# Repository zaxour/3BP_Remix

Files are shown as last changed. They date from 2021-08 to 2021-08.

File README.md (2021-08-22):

# 3BP_Remix
Modified version of Tian Feng/dB_Electronics triple bypass v2 board

Incorporates 5.6k pull up resistors for the RGB lines, as Model 1 3BP installs lift the VDP pins to isolate them from the Genesis/MD PCB. Based on research by Tian Feng, and subsequently verified by myself by looking at all available schematics for the Model 1 Genesis/MD, this causes a loss of fidelity in color transitions.

The positioning of the Mini DIN has also been adjusted to fit alongside the Model 1's existing video connector.

Files provided are compatible with Autodesk Eagle (Fusion 360).

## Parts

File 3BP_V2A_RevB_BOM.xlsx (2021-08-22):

Qty | Value | Package | Parts
6 | 0.1u | C0603 | C1, C2, C3, C4, C5, C6 | v
2 | 150p | C0603 | C18, C19 | v
6 | 1u | C0603 | C10, C11, C12, C13, C14, C15 | v
2 | 10u | C0805 | C9, C16 | v
1 | 10u | C1206 | C17 | v
1 | 22u | C1206 | C7 | v
1 | 220u | CT3528 | C8 | v
2 | 47u | CT3528 | C21, C22 | v
1 | MD-90SM | MD90SM | CN1
2 | 100k | R0603 | R29, R32 | v
4 | 10k | R0603 | R26, R27, R30, R33 | v
2 | 130k | R0603 | R28, R31 | v
4 | 1k | R0603 | R6, R7, R8, R9 | v
2 | 2.2k | R0603 | R1, R15 | v
6 | 210k | R0603 | R20, R21, R22, R23, R24, R25 | v
2 | 300k | R0603 | R34, R35 | v
2 | 330 | R0603 | R36, R37 | v
1 | 4.7k | R0603 | R10 | v
7 | 5.62k | R0603 | R2, R3, R4, R5, R38, R39, R40 | v
5 | 75 | R0603 | R11, R13, R14, R17, R18 | v
1 | 750 | R0603 | R16 | v
1 | TL972 | SOIC8 | IC2 | v
1 | THS7374IPWR | TSSOP14 | IC1
https://www.digikey.com/short/43w8t24t

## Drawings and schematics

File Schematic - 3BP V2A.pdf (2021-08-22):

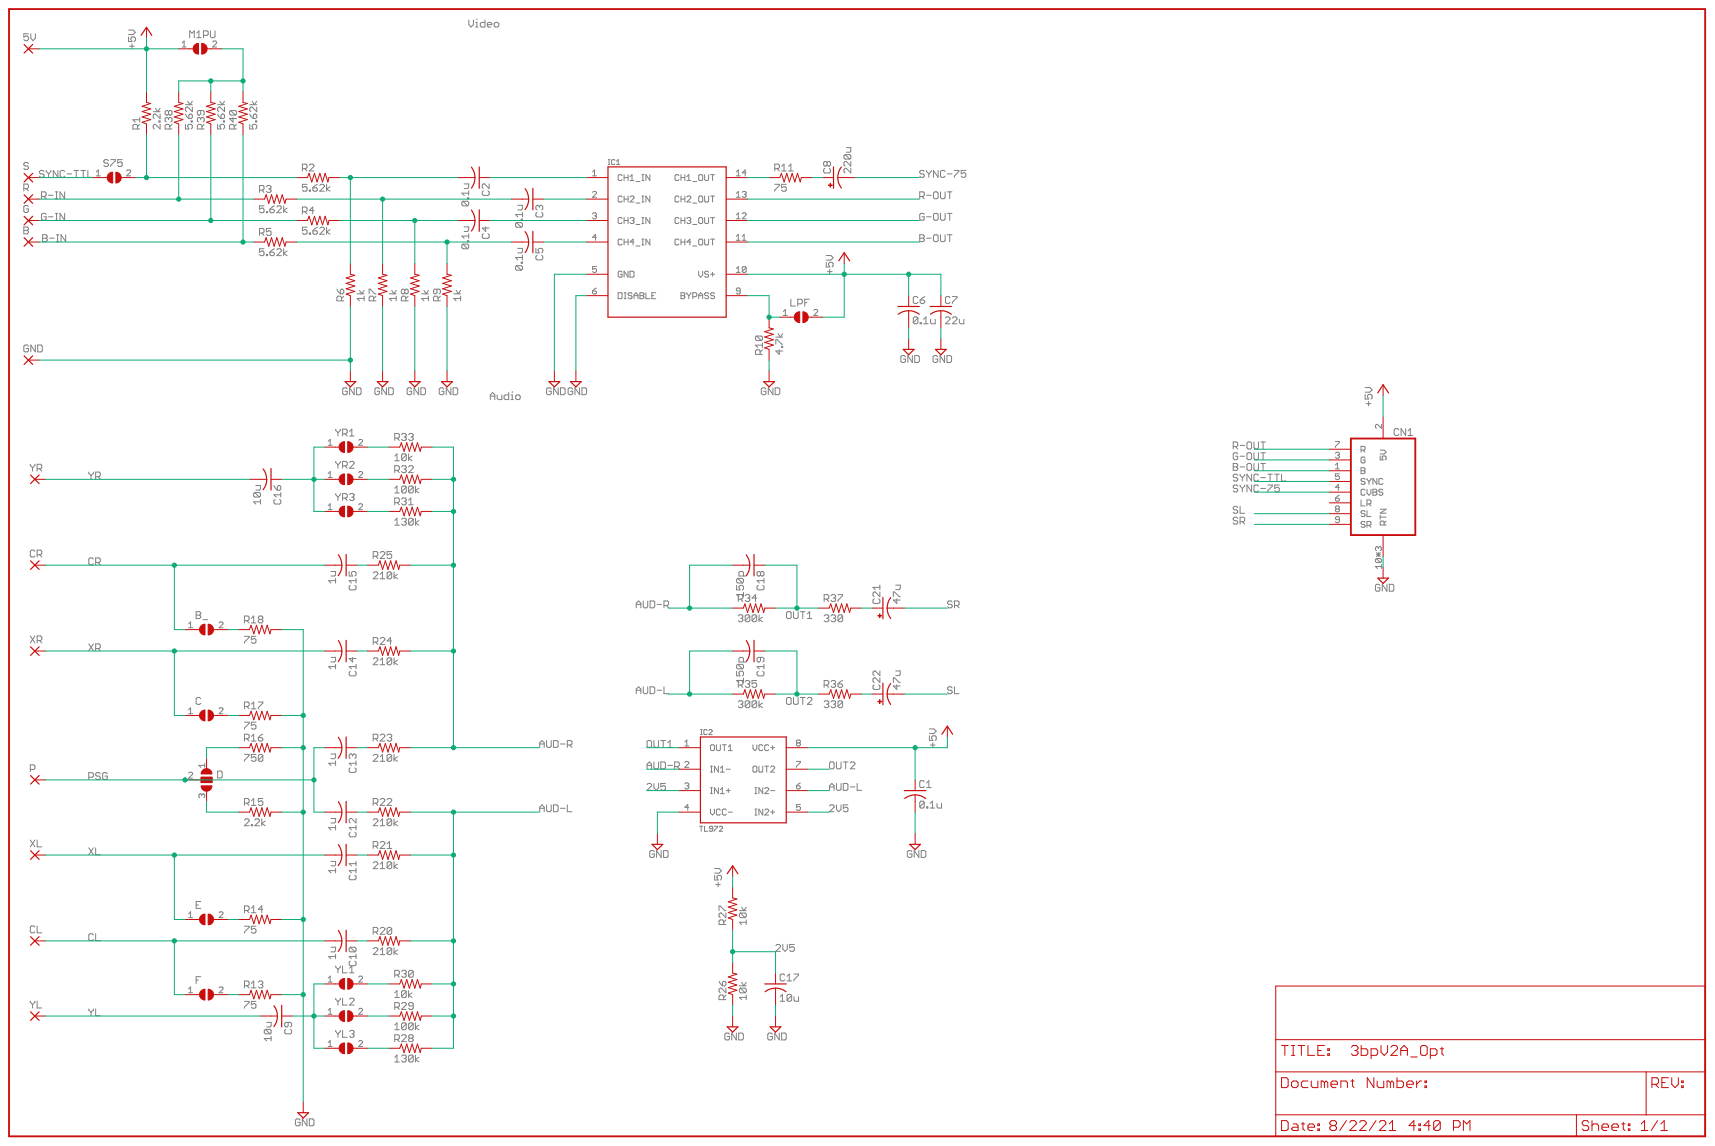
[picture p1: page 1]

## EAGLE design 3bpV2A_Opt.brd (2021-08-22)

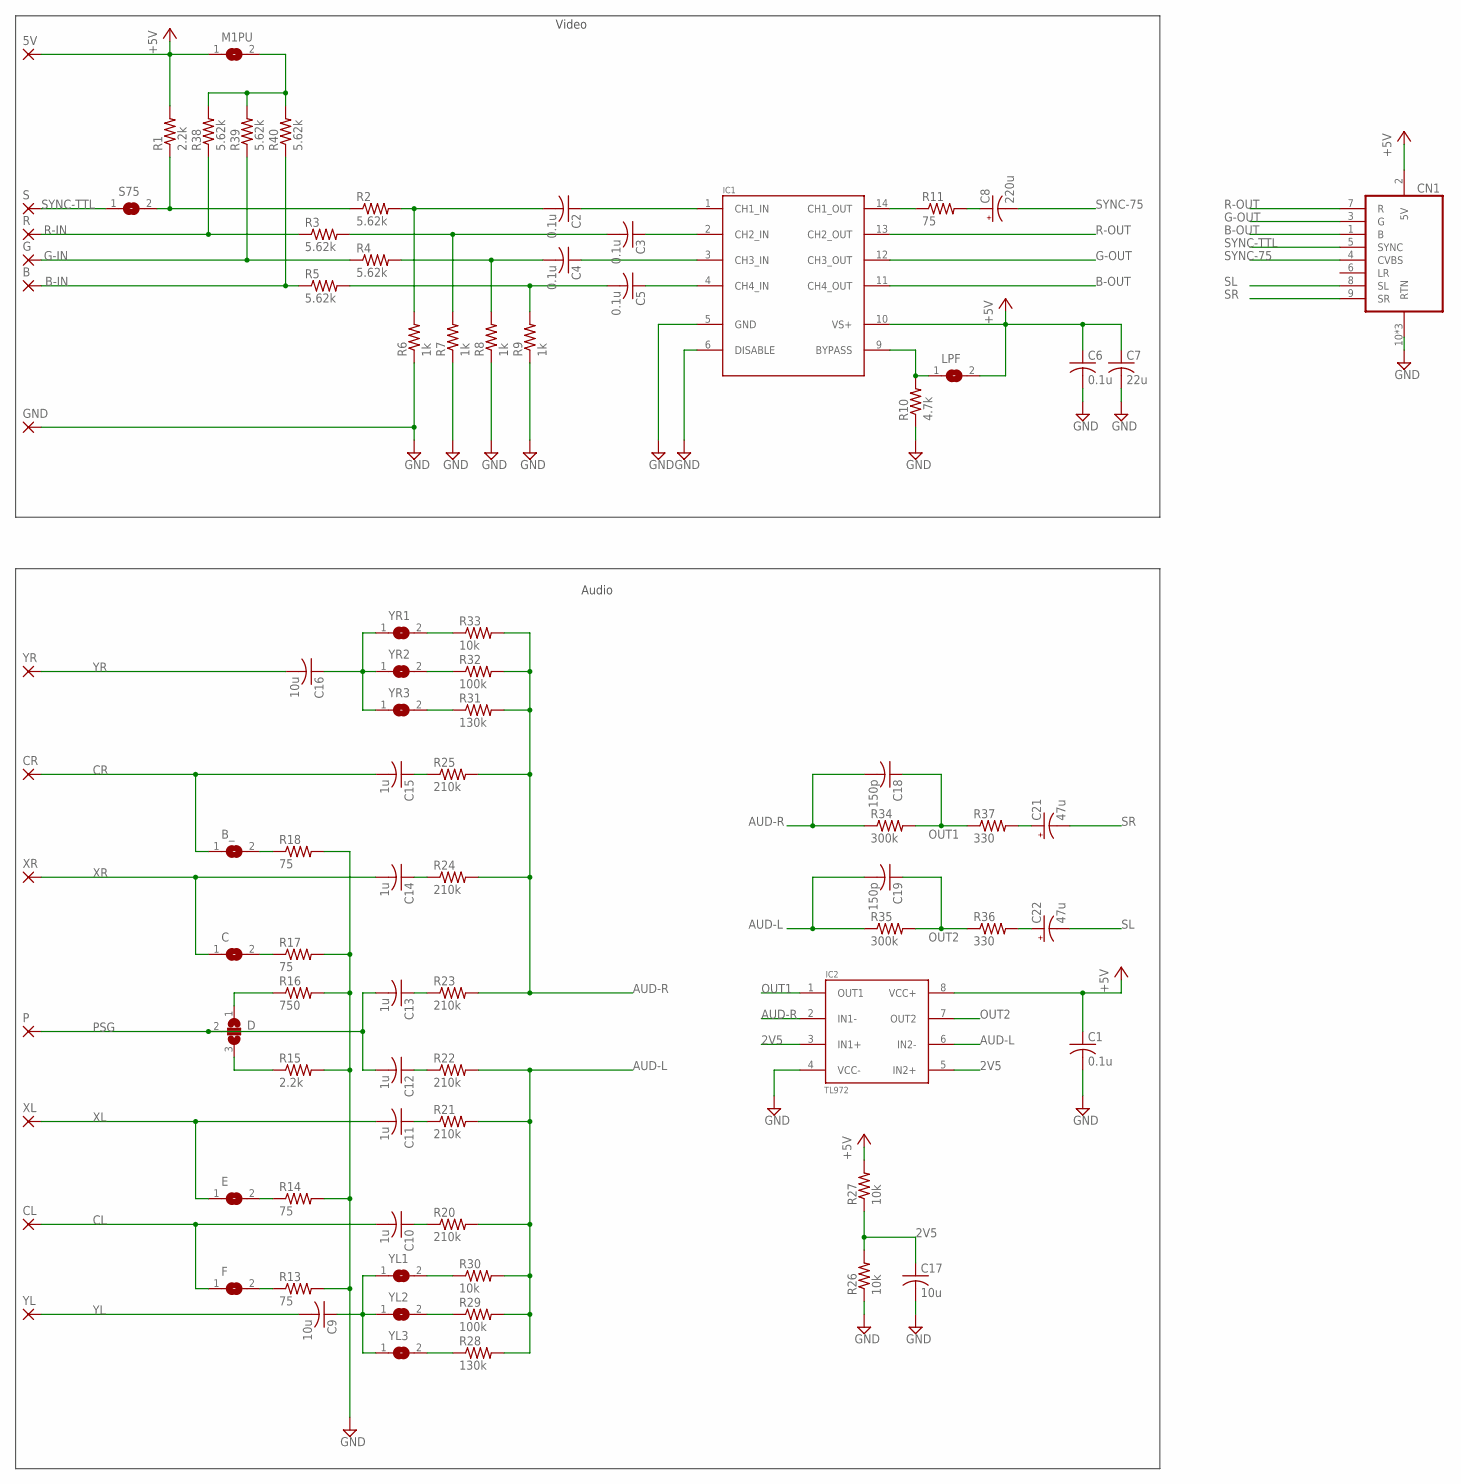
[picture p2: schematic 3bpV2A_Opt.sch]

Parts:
5V: SMD2; SMD1,27-2,54
B: SMD2; SMD1,27-2,54
B_: SMD_J; SJ
C: SMD_J; SJ
C1, C2, C3, C4, C5, C6: 0.1u; C0603
C7: 22u; C1206
C8: 220u; CT3528
C9, C16: 10u; C0805
C10, C11, C12, C13, C14, C15: 1u; C0603
C17: 10u; C1206
C18, C19: 150p; C0603
C21, C22: 47u; CT3528
CL: SMD2; SMD1,27-2,54
CN1: MD-90SM; MD90SM
CR: SMD2; SMD1,27-2,54
D: SMD_J2; SJ_2
E: SMD_J; SJ
F: SMD_J; SJ
G: SMD2; SMD1,27-2,54
GND: SMD2; SMD1,27-2,54
IC1: THS7374IPWR; TSSOP14
IC2: TL972; SOIC8
LPF: SMD_J; SJ
M1PU: SMD_J; SJ
P: SMD2; SMD1,27-2,54
R: SMD2; SMD1,27-2,54
R1, R15: 2.2k; R0603
R2, R3, R4, R5, R38, R39, R40: 5.62k; R0603
R6, R7, R8, R9: 1k; R0603
R10: 4.7k; R0603
R11, R13, R14, R17, R18: 75; R0603
R16: 750; R0603
R20, R21, R22, R23, R24, R25: 210k; R0603
R26, R27, R30, R33: 10k; R0603
R28, R31: 130k; R0603
R29, R32: 100k; R0603
R34, R35: 300k; R0603
R36, R37: 330; R0603
S: SMD2; SMD1,27-2,54
S75: SMD_J; SJ
XL: SMD2; SMD1,27-2,54
XR: SMD2; SMD1,27-2,54
YL: SMD2; SMD1,27-2,54
YL1, YL2, YL3: SMD_J; SJ
YR: SMD2; SMD1,27-2,54
YR1, YR2, YR3: SMD_J; SJ

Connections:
2V5: C17.1, IC2.3 (IN1+), IC2.5 (IN2+), R26.2, R27.1
+5V: 5V.1, C1.1, C6.1, C7.1, CN1.2 (5V), IC1.10 (VS+), IC2.8 (VCC+), LPF.2, M1PU.1, R1.2, R27.2
AUD-L: C19.2, IC2.6 (IN2-), R20.2, R21.2, R22.2, R28.2, R29.2, R30.2, R35.1
AUD-R: C18.2, IC2.2 (IN1-), R23.2, R24.2, R25.2, R31.2, R32.2, R33.2, R34.1
B-IN: B.1, R5.1, R40.1
B-OUT: CN1.1 (B), IC1.11 (CH4_OUT)
CL: C10.2, CL.1, F.1
CR: B_.1, C15.2, CR.1
G-IN: G.1, R4.1, R39.1
G-OUT: CN1.3 (G), IC1.12 (CH3_OUT)
GND: C1.2, C6.2, C7.2, C17.2, CN1.10 (RTN), CN1.11 (RTN), CN1.12 (RTN), GND.1, IC1.5 (GND), IC1.6 (DISABLE), IC2.4 (VCC-), R6.1, R7.1, R8.1, R9.1, R10.1, R13.2, R14.2, R15.2, R16.2, R17.2, R18.2, R26.1
unnamed: C2.2, R2.2, R6.2
unnamed: C2.1, IC1.1 (CH1_IN)
unnamed: C3.2, R3.2, R7.2
unnamed: C3.1, IC1.2 (CH2_IN)
unnamed: C4.2, R4.2, R8.2
unnamed: C4.1, IC1.3 (CH3_IN)
unnamed: C5.1, IC1.4 (CH4_IN)
unnamed: C5.2, R5.2, R9.2
unnamed: IC1.9 (BYPASS), LPF.1, R10.2
unnamed: M1PU.2, R38.2, R39.2, R40.2
unnamed: B_.2, R18.1
unnamed: R1.1, R2.1, S75.2
unnamed: IC1.14 (CH1_OUT), R11.1
unnamed: C8.+, R11.2
unnamed: C16.1, YR1.1, YR2.1, YR3.1
unnamed: R33.1, YR1.2
unnamed: R32.1, YR2.2
unnamed: R31.1, YR3.2
unnamed: E.2, R14.1
unnamed: C15.1, R25.1
unnamed: C.2, R17.1
unnamed: C14.1, R24.1
unnamed: D.3, R15.1
unnamed: D.1, R16.1
unnamed: C13.1, R23.1
unnamed: C12.1, R22.1
unnamed: C11.1, R21.1
unnamed: F.2, R13.1
unnamed: C10.1, R20.1
unnamed: C9.1, YL1.1, YL2.1, YL3.1
unnamed: R30.1, YL1.2
unnamed: R29.1, YL2.2
unnamed: R28.1, YL3.2
unnamed: C22.+, R36.2
unnamed: C21.+, R37.2
OUT1: C18.1, IC2.1 (OUT1), R34.2, R37.1
OUT2: C19.1, IC2.7 (OUT2), R35.2, R36.1
PSG: C12.2, C13.2, D.2, P.1
R-IN: R.1, R3.1, R38.1
R-OUT: CN1.7 (R), IC1.13 (CH2_OUT)
SL: C22.-, CN1.8 (SL)
SR: C21.-, CN1.9 (SR)
SYNC-75: C8.-, CN1.4 (CVBS)
SYNC-TTL: CN1.5 (SYNC), S.1, S75.1
XL: C11.2, E.1, XL.1
XR: C.1, C14.2, XR.1
YL: C9.2, YL.1
YR: C16.2, YR.1

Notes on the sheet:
Audio
Video

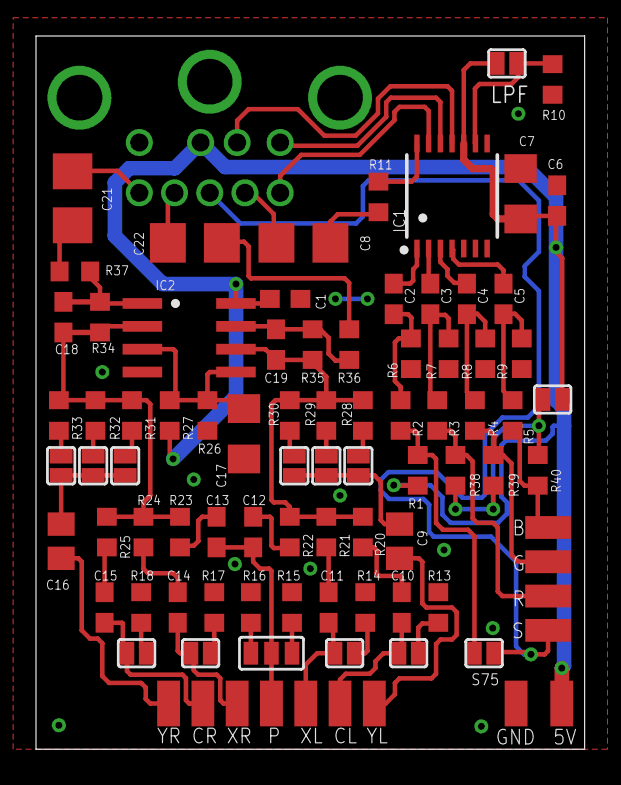
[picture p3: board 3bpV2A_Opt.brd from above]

Board: 2 copper layers, 30.5 x 39.6 mm, 89 parts (1 on the bottom side), 59 nets.

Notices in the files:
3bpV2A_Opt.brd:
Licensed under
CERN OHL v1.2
